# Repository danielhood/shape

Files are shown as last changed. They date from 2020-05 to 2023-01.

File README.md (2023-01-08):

# shape
Analog audio shaping toys. Line level moudles as opposed to eurorack i/o, but operating on +12/-12 power rails. The panels are built to be housed in 3U eurorack cases for the power supplies, but use 1/4" audio connectors. 

## 	saturation
A tape saturation/distortion unit based on: http://zadvitsky.com/index.php/studio-devices/tape-saturation-compressor.html
This was built and wired in as a bypassable 2nd stage to the var_state_eq module. A future revision would likely have a blend pot to add in the saturated signal from the EQ'd signal (need to review phase issues).

## var_state_eq
A State Variable Filter 2 Band EQ moudle based on the CALREC PQ1549 (only the HMF and LMF circuits), adapted from: https://www.gyraf.dk/gy_pd/calreq/calrec.htm

## compression
A compressor. WIP. Will be based on a few existing things; other than op-amps, will be discrete components (no THAT chips, etc.).

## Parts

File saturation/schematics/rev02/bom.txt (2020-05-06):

Partlist exported from /Users/dhood/git/danielhood/shape/saturation/schematics/rev01/saturation.main.sch at 2020-05-05 8:48 PM

Qty Value  Device           Package      Parts                  Description                       MF MPN OC_FARNELL OC_NEWARK POPULARITY
3   0.1uF  CC-US025-024X044 C025-024X044 C1, C2, C5             CAPACITOR, US symbol                                                    
3   100uF  CE-USE5-8.5      E5-8,5       C3, C4, C8             ELECTROLYTIC CAPACITOR, US symbol                                       
4   10K    R                0207/7       R1, R9, R10, R13       RESISTOR, US symbol                                                     
2   1M     R                0207/7       R4, R6                 RESISTOR, US symbol                                                     
6   1N270  1N270            DO07         D3, D4, D5, D6, D7, D8 DIODE                                                         0         
2   1N4148 1N4148           DO34-5       D1, D2                 DIODE                                                                   
1   2.2K   R                0207/7       R7                     RESISTOR, US symbol                                                     
1   2.2nF  CC-US025-024X044 C025-024X044 C6                     CAPACITOR, US symbol                                                    
4   200K   3RP/1610N        3RP/1610N    R5, R8, R12, R14       Generic single level pcb pot.                                 8         
3   22K    R                0207/7       R2, R3, R11            RESISTOR, US symbol                                                     
1   22nF   CC-US025-024X044 C025-024X044 C7                     CAPACITOR, US symbol                                                    
1   IN     JACK-M           JACK-M       J1                                                                                             
1   OUT    JACK-M           JACK-M       J2                                                                                             
1   PWR    PINHD-2X5        2X05         JP1                    PIN HEADER                                                    35        
1   S1     DS01             DS-01        S1                     DIL/CODE SWITCH                          unknown    unknown             
1   S2     DS01             DS-01        S2                     DIL/CODE SWITCH                          unknown    unknown             
1   S3     DS01             DS-01        S3                     DIL/CODE SWITCH                          unknown    unknown             
1   TL084P TL084P           DIL14        IC1                    OP AMP

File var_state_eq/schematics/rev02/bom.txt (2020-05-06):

Partlist exported from /Users/dhood/git/danielhood/shape/var_state_eq/schematics/rev01/var_state_eq.sch at 2020-05-05 8:44 PM

Qty Value   Device           Package      Parts                                                    Description                       POPULARITY
5   0.1u    CC-US025-024X044 C025-024X044 C1, C2, C3, C4, C5                                       CAPACITOR, US symbol                        
5   100K    R                0207/7       R4, R7, R9, R19, R24                                     RESISTOR, US symbol                         
2   100n    CC-US025-024X044 C025-024X044 C9, C17                                                  CAPACITOR, US symbol                        
2   100p    CC-US025-024X044 C025-024X044 C14, C19                                                 CAPACITOR, US symbol                        
3   100u    CE-USE5-8.5      E5-8,5       C7, C8, C18                                              ELECTROLYTIC CAPACITOR, US symbol           
3   10K     R                0207/7       R1, R2, R3                                               RESISTOR, US symbol                         
2   10K LIN R-VAR-PANEL      R-VAR-PANEL  RV2, RV4                                                 Panel mounted pot                           
3   18p     CC-US025-024X044 C025-024X044 C6, C15, C23                                             CAPACITOR, US symbol                        
4   1K      R                0207/7       R17, R27, R29, R34                                       RESISTOR, US symbol                         
12  20K     R                0207/7       R5, R6, R10, R12, R13, R14, R15, R18, R23, R25, R28, R33 RESISTOR, US symbol                         
1   22R     R                0207/7       R26                                                      RESISTOR, US symbol                         
2   22n     CC-US050-024X044 C050-024X044 C20, C21                                                 CAPACITOR, US symbol                        
2   22u     CE-USE2-5        E2-5         C10, C13                                                 ELECTROLYTIC CAPACITOR, US symbol           
3   33u     CE-USE2-5        E2-5         C11, C12, C16                                            ELECTROLYTIC CAPACITOR, US symbol           
4   5.1K    R                0207/7       R8, R11, R16, R22                                        RESISTOR, US symbol                         
4   50K     R                0207/7       R21, R31, R32, R35                                       RESISTOR, US symbol                         
2   50K LOG 3RP/1610G        3RP/1610G    R20, R30                                                 Generic two level pot.            2         
2   50K LOG R-VAR-PANEL      R-VAR-PANEL  RV1, RV3                                                 Panel mounted pot                           
2   68n     CC-US050-024X044 C050-024X044 C22, C24                                                 CAPACITOR, US symbol                        
1   IN      JACK-M           JACK-M       J1                                                                                                   
1   OUT     JACK-M           JACK-M       J2                                                                                                   
1   PWR     PINHD-2X5        2X05         JP1                                                      PIN HEADER                        35        
3   TL084P  TL084P           DIL14        IC1, IC2, IC3                                            OP AMP

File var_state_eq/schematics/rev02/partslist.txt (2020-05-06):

Partlist

Exported from var_state_eq.sch at 2020-05-05 8:42 PM

EAGLE Version 9.5.1 Copyright (c) 1988-2019 Autodesk, Inc.

Assembly variant: 

Part     Value          Device           Package      Library  Sheet

C1       0.1u           CC-US025-024X044 C025-024X044 _common  1
C2       0.1u           CC-US025-024X044 C025-024X044 _common  1
C3       0.1u           CC-US025-024X044 C025-024X044 _common  1
C4       0.1u           CC-US025-024X044 C025-024X044 _common  1
C5       0.1u           CC-US025-024X044 C025-024X044 _common  1
C6       18p            CC-US025-024X044 C025-024X044 _common  1
C7       100u           CE-USE5-8.5      E5-8,5       _common  1
C8       100u           CE-USE5-8.5      E5-8,5       _common  1
C9       100n           CC-US025-024X044 C025-024X044 _common  1
C10      22u            CE-USE2-5        E2-5         _common  1
C11      33u            CE-USE2-5        E2-5         _common  1
C12      33u            CE-USE2-5        E2-5         _common  1
C13      22u            CE-USE2-5        E2-5         _common  1
C14      100p           CC-US025-024X044 C025-024X044 _common  1
C15      18p            CC-US025-024X044 C025-024X044 _common  1
C16      33u            CE-USE2-5        E2-5         _common  1
C17      100n           CC-US025-024X044 C025-024X044 _common  1
C18      100u           CE-USE5-8.5      E5-8,5       _common  1
C19      100p           CC-US025-024X044 C025-024X044 _common  1
C20      22n            CC-US050-024X044 C050-024X044 _common  1
C21      22n            CC-US050-024X044 C050-024X044 _common  1
C22      68n            CC-US050-024X044 C050-024X044 _common  1
C23      18p            CC-US025-024X044 C025-024X044 _common  1
C24      68n            CC-US050-024X044 C050-024X044 _common  1
IC1      TL084P         TL084P           DIL14        _common  1
IC2      TL084P         TL084P           DIL14        _common  1
IC3      TL084P         TL084P           DIL14        _common  1
J1       IN             JACK-M           JACK-M       _common  1
J2       OUT            JACK-M           JACK-M       _common  1
JP1      PWR            PINHD-2X5        2X05         pinhead  1
R1       10K            R                0207/7       _common  1
R2       10K            R                0207/7       _common  1
R3       10K            R                0207/7       _common  1
R4       100K           R                0207/7       _common  1
R5       20K            R                0207/7       _common  1
R6       20K            R                0207/7       _common  1
R7       100K           R                0207/7       _common  1
R8       5.1K           R                0207/7       _common  1
R9       100K           R                0207/7       _common  1
R10      20K            R                0207/7       _common  1
R11      5.1K           R                0207/7       _common  1
R12      20K            R                0207/7       _common  1
R13      20K            R                0207/7       _common  1
R14      20K            R                0207/7       _common  1
R15      20K            R                0207/7       _common  1
R16      5.1K           R                0207/7       _common  1
R17      1K             R                0207/7       _common  1
R18      20K            R                0207/7       _common  1
R19      100K           R                0207/7       _common  1
R20      50K LOG        3RP/1610G        3RP/1610G    _common  1
R21      50K            R                0207/7       _common  1
R22      5.1K           R                0207/7       _common  1
R23      20K            R                0207/7       _common  1
R24      100K           R                0207/7       _common  1
R25      20K            R                0207/7       _common  1
R26      22R            R                0207/7       _common  1
R27      1K             R                0207/7       _common  1
R28      20K            R                0207/7       _common  1
R29      1K             R                0207/7       _common  1
R30      50K LOG        3RP/1610G        3RP/1610G    _common  1
R31      50K            R                0207/7       _common  1
R32      50K            R                0207/7       _common  1
R33      20K            R                0207/7       _common  1
R34      1K             R                0207/7       _common  1
R35      50K            R                0207/7       _common  1
RV1      50K LOG        R-VAR-PANEL      R-VAR-PANEL  _common  1
RV2      10K LIN        R-VAR-PANEL      R-VAR-PANEL  _common  1
RV3      50K LOG        R-VAR-PANEL      R-VAR-PANEL  _common  1
RV4      10K LIN        R-VAR-PANEL      R-VAR-PANEL  _common  1

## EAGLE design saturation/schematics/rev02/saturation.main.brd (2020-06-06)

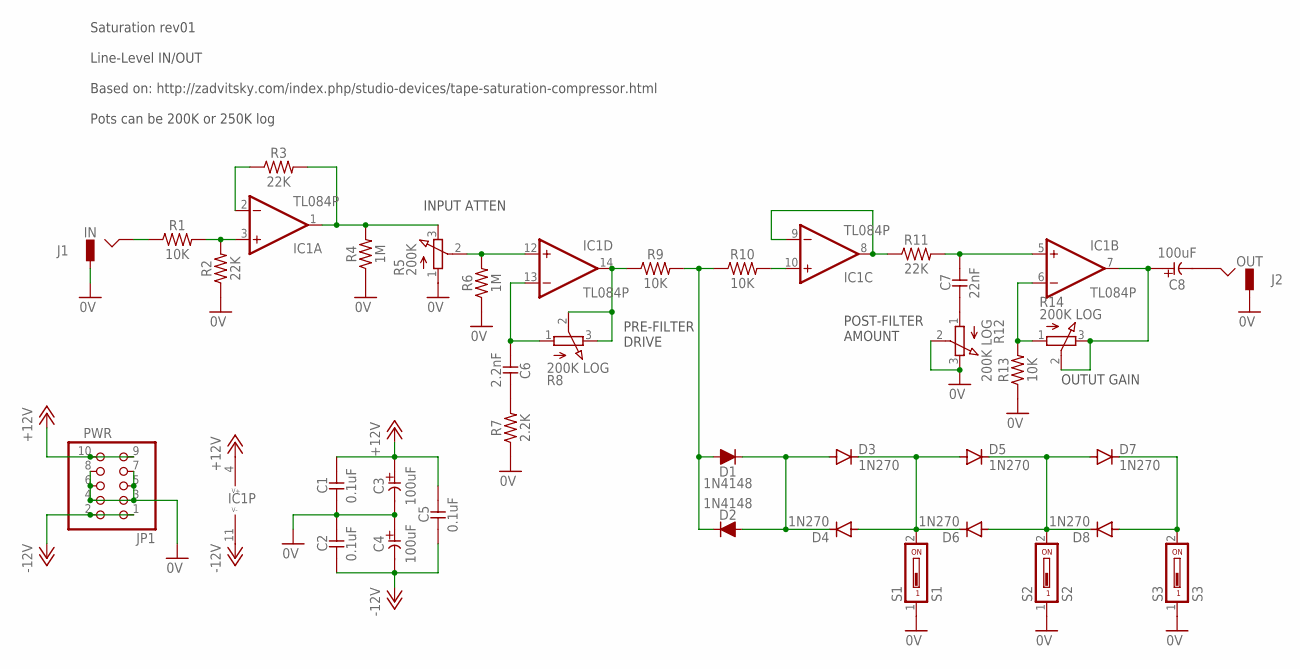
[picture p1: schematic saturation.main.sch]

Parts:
C1, C2, C5: 0.1uF; C025-024X044
C3, C4, C8: 100uF; E5-8,5
C6: 2.2nF; C025-024X044
C7: 22nF; C025-024X044
D1, D2: 1N4148; DO34-5
D3, D4, D5, D6, D7, D8: 1N270; DO07
IC1: TL084P; DIL14
J1: IN; JACK-M
J2: OUT; JACK-M
JP1: PWR; 2X05
R1, R9, R10, R13: 10K; 0207/7
R2, R3, R11: 22K; 0207/7
R4, R6: 1M; 0207/7
R5: 200K; 3RP/1610N
R7: 2.2K; 0207/7
R8, R12, R14: 200K LOG; 3RP/1610N
S1: S1; DS-01
S2: S2; DS-01
S3: S3; DS-01

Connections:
0V: C1.2, C2.1, C3.-, C4.+, J1.GND, J2.GND, JP1.3, JP1.4, JP1.5, JP1.6, JP1.7, JP1.8, R2.1, R4.1, R5.1 (A), R6.1, R7.1, R12.2 (S), R12.3 (E), R13.1, S1.1, S2.1, S3.1
+12V: C1.1, C3.+, C5.1, IC1.4 (V+), JP1.9, JP1.10
-12V: C2.2, C4.-, C5.2, IC1.11 (V-), JP1.1, JP1.2
unnamed: D1.A, D2.C, R9.2, R10.1
unnamed: C7.2, R12.1 (A)
unnamed: D1.C, D2.A, D3.A, D4.C
unnamed: D3.C, D4.A, D5.A, D6.C, S1.2
unnamed: IC1.10 (+IN), R10.2
unnamed: D5.C, D6.A, D7.A, D8.C, S2.2
unnamed: IC1.8 (OUT), IC1.9 (-IN), R11.1
unnamed: D7.C, D8.A, S3.2
unnamed: C7.1, IC1.5 (+IN), R11.2
unnamed: IC1.6 (-IN), R13.2, R14.1 (A)
unnamed: C8.+, IC1.7 (OUT), R14.2 (S), R14.3 (E)
unnamed: C8.-, J2.HOT
unnamed: IC1.14 (OUT), R8.2 (S), R8.3 (E), R9.1
unnamed: C6.1, R7.2
unnamed: J1.HOT, R1.1
unnamed: IC1.3 (+IN), R1.2, R2.2
unnamed: IC1.2 (-IN), R3.1
unnamed: IC1.1 (OUT), R3.2, R4.2, R5.3 (E)
unnamed: C6.2, IC1.13 (-IN), R8.1 (A)
unnamed: IC1.12 (+IN), R5.2 (S), R6.2

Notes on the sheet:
Saturation rev01 Line-Level IN/OUT Based on: http://zadvitsky.com/index.php/studio-devices/tape-saturation-compressor.html Pots can be 200K or 250K log
PRE-FILTER DRIVE
POST-FILTER AMOUNT
INPUT ATTEN
OUTUT GAIN

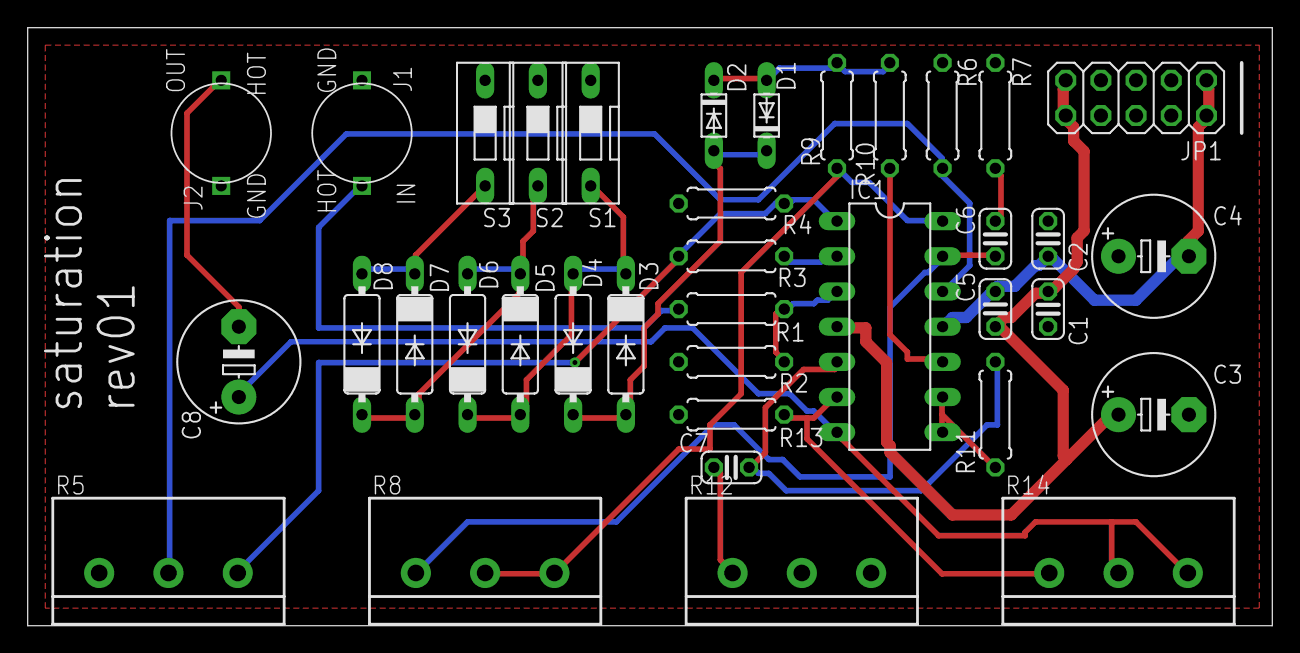
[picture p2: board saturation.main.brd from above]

Board: 2 copper layers, 89.8 x 43.2 mm, 37 parts (0 on the bottom side), 23 nets.

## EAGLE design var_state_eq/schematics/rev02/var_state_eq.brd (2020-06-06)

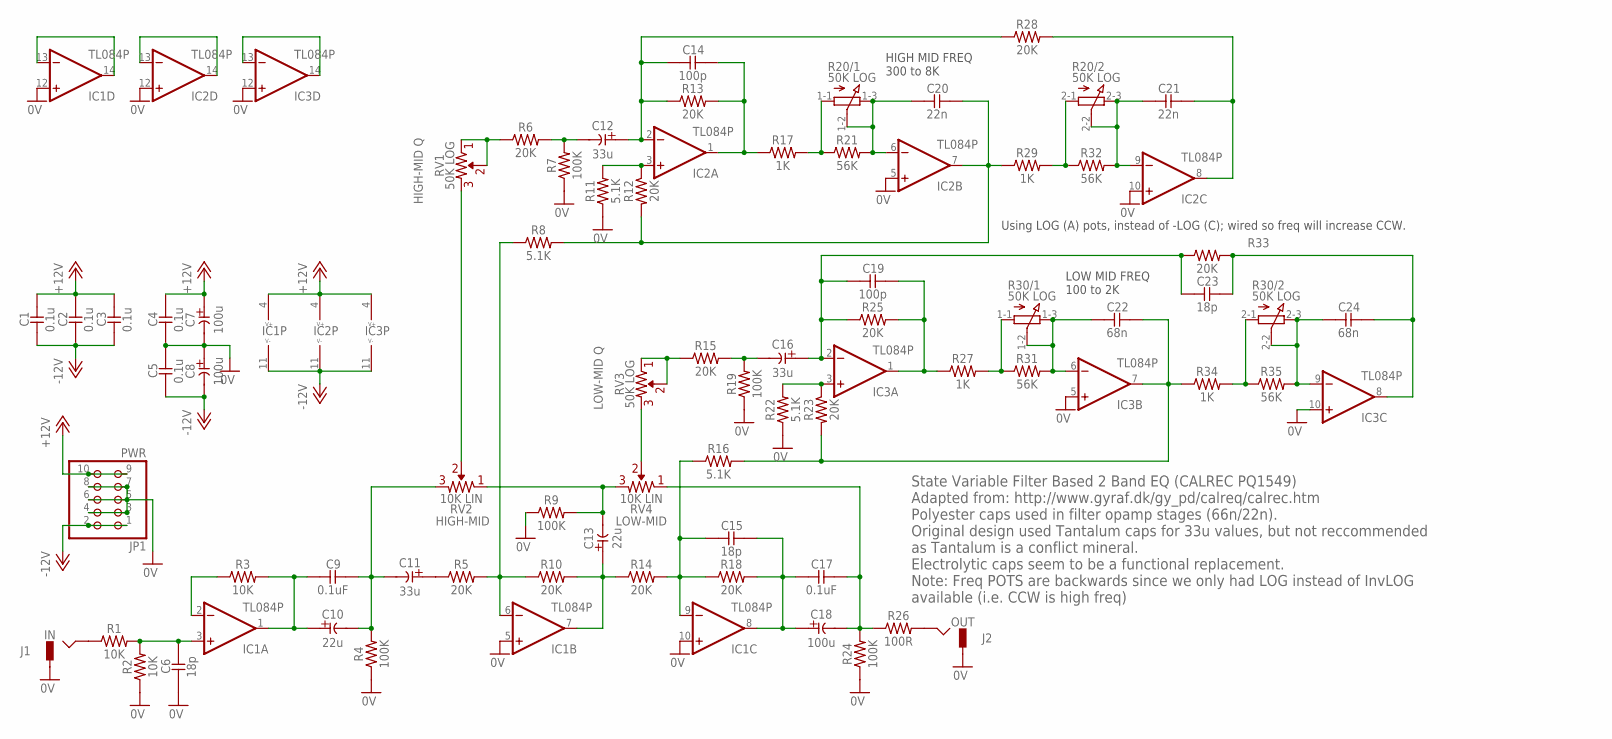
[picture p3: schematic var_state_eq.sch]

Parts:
C1, C2, C3, C4, C5: 0.1u; C025-024X044
C6, C15, C23: 18p; C025-024X044
C7, C8, C18: 100u; E5-8,5
C9, C17: 0.1uF; C025-024X044
C10, C13: 22u; E2-5
C11, C12, C16: 33u; E2-5
C14, C19: 100p; C025-024X044
C20, C21: 22n; C050-024X044
C22, C24: 68n; C050-024X044
IC1, IC2, IC3: TL084P; DIL14
J1: IN; JACK-M
J2: OUT; JACK-M
JP1: PWR; 2X05
R1, R2, R3: 10K; 0207/7
R4, R7, R9, R19, R24: 100K; 0207/7
R5, R6, R10, R12, R13, R14, R15, R18, R23, R25, R28, R33: 20K; 0207/7
R8, R11, R16, R22: 5.1K; 0207/7
R17, R27, R29, R34: 1K; 0207/7
R20, R30: 50K LOG; 3RP/1610G
R21, R31, R32, R35: 56K; 0207/7
R26: 100R; 0207/7
RV1, RV3: 50K LOG; R-VAR-PANEL
RV2, RV4: 10K LIN; R-VAR-PANEL

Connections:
0V: C4.2, C5.1, C6.2, C7.-, C8.+, IC1.5 (+IN), IC1.10 (+IN), IC1.12 (+IN), IC2.5 (+IN), IC2.10 (+IN), IC2.12 (+IN), IC3.5 (+IN), IC3.10 (+IN), IC3.12 (+IN), J1.GND, J2.GND, JP1.3, JP1.4, JP1.5, JP1.6, JP1.7, JP1.8, R2.1, R4.1, R7.1, R9.1, R11.1, R19.1, R22.1, R24.1
+12V: C1.1, C2.1, C3.1, C4.1, C7.+, IC1.4 (V+), IC2.4 (V+), IC3.4 (V+), JP1.9, JP1.10
-12V: C1.2, C2.2, C3.2, C5.2, C8.-, IC1.11 (V-), IC2.11 (V-), IC3.11 (V-), JP1.1, JP1.2
unnamed: IC1.13 (-IN), IC1.14 (OUT)
unnamed: IC2.13 (-IN), IC2.14 (OUT)
unnamed: IC3.13 (-IN), IC3.14 (OUT)
unnamed: C11.+, R5.1
unnamed: J1.HOT, R1.1
unnamed: IC1.2 (-IN), R3.1
unnamed: C13.-, R9.2, RV2.R1 (1), RV4.R2 (2)
unnamed: C9.1, C10.-, C11.-, R4.2, RV2.R2 (2)
unnamed: C6.1, IC1.3 (+IN), R1.2, R2.2
unnamed: C13.+, IC1.7 (OUT), R10.2, R14.1
unnamed: C9.2, C10.+, IC1.1 (OUT), R3.2
unnamed: RV1.R2 (2), RV2.VAR
unnamed: IC1.6 (-IN), R5.2, R8.1, R10.1
unnamed: J2.HOT, R26.2
unnamed: C15.2, IC1.9 (-IN), R14.2, R16.1, R18.1
unnamed: C17.1, C18.-, R24.2, R26.1, RV4.R1 (1)
unnamed: R6.1, RV1.R1 (1), RV1.VAR
unnamed: C15.1, C17.2, C18.+, IC1.8 (OUT), R18.2
unnamed: C12.-, R6.2, R7.2
unnamed: C12.+, C14.2, IC2.2 (-IN), R13.1, R28.1
unnamed: C14.1, IC2.1 (OUT), R13.2, R17.1
unnamed: R17.2, R20.1-1 (A), R21.1
unnamed: C20.2, IC2.6 (-IN), R20.1-2 (S), R20.1-3 (E), R21.2
unnamed: R20.2-1 (A), R29.2, R32.1
unnamed: C20.1, IC2.7 (OUT), R8.2, R12.2, R29.1
unnamed: RV3.R2 (2), RV4.VAR
unnamed: C21.2, IC2.9 (-IN), R20.2-2 (S), R20.2-3 (E), R32.2
unnamed: C21.1, IC2.8 (OUT), R28.2
unnamed: IC3.3 (+IN), R22.2, R23.1
unnamed: R15.1, RV3.R1 (1), RV3.VAR
unnamed: C16.-, R15.2, R19.2
unnamed: C16.+, C19.2, C23.2, IC3.2 (-IN), R25.1, R33.1
unnamed: C22.1, IC3.7 (OUT), R16.2, R23.2, R34.1
unnamed: C19.1, IC3.1 (OUT), R25.2, R27.1
unnamed: R27.2, R30.1-1 (A), R31.1
unnamed: C22.2, IC3.6 (-IN), R30.1-2 (S), R30.1-3 (E), R31.2
unnamed: R30.2-1 (A), R34.2, R35.1
unnamed: C24.2, IC3.9 (-IN), R30.2-2 (S), R30.2-3 (E), R35.2
unnamed: C23.1, C24.1, IC3.8 (OUT), R33.2
unnamed: IC2.3 (+IN), R11.2, R12.1

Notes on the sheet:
State Variable Filter Based 2 Band EQ (CALREC PQ1549) Adapted from: http://www.gyraf.dk/gy_pd/calreq/calrec.htm Polyester caps used in filter opamp stages (66n/22n). Original design used Tantalum caps for 33u values, but not reccommended as Tantalum is a conflict mineral. Electrolytic caps seem to 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
HIGH MID FREQ 300 to 8K
HIGH-MID Q
LOW-MID Q
LOW MID FREQ 100 to 2K
Using LOG (A) pots, instead of -LOG (C); wired so freq will increase CCW.
HIGH-MID
LOW-MID

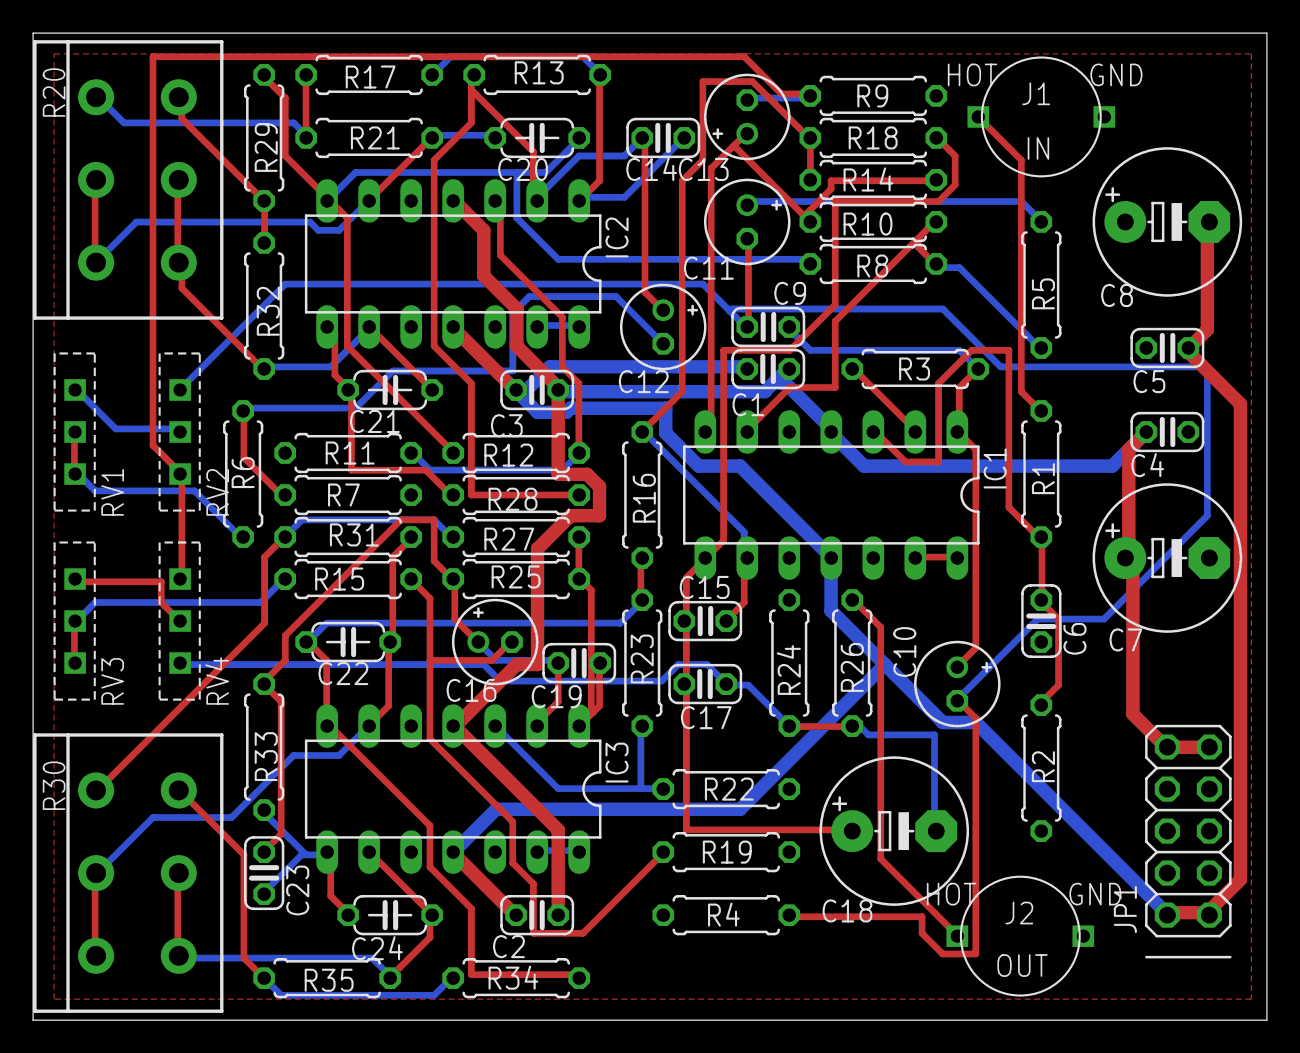
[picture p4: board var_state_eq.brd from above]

Board: 2 copper layers, 74.6 x 59.7 mm, 69 parts (0 on the bottom side), 43 nets.

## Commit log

2020-03-19 Initial add of saturation schem and libs
    [saturation.main.sch]
2020-03-19 Inital saturation board layout
    [saturation.main.brd, saturation.main.sch]
2020-03-19 Routing for saturation
    [saturation.main.brd, saturation.main.sch]
2020-03-22 Consolidate power on saturation board
    [saturation.main.brd, saturation.main.sch]
2020-03-22 Saturation schem review
    [saturation.main.brd, saturation.main.sch]
2020-03-23 Inital add for 2 Band EQ
    [var_state_eq.sch]
2020-03-24 EQ schem review
    [var_state_eq.sch]
2020-05-03 Updated EQ labels
    [var_state_eq.sch]
2020-05-03 Updated EQ with as-build values
    [var_state_eq.sch]
2020-05-04 Added routed board; switched to film caps
    [var_state_eq.brd, var_state_eq.sch]
2020-05-06 Updates for part purchase
    [bom.csv, var_state_eq.brd, var_state_eq.sch]
2020-05-31 Update pot values
    [saturation.main.brd, saturation.main.sch]
2020-05-31 Updated resistor values to 56K
    [var_state_eq.brd, var_state_eq.sch]
2020-05-31 Updated cap values
    [var_state_eq.brd, var_state_eq.sch]
2020-06-06 Cam files and packaged gerbers for rev01
2020-06-06 Created rev02
    [bom.csv, saturation.main.brd, saturation.main.sch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]
2020-06-06 Flipped sat atten pot
    [saturation.main.brd, saturation.main.sch]
2023-01-08 Added Compressor POC schem; updated readme
    [compressor_poc.sch]
2023-01-08 Updated values from amp build
    [compressor_poc.sch]
2023-01-09 Added vca to compressor poc schem
    [compressor_poc.sch]
2023-01-11 Updated comp vca values from test build
    [compressor_poc.sch]
